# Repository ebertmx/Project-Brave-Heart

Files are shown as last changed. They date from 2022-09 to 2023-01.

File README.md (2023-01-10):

# Project Brave Heart
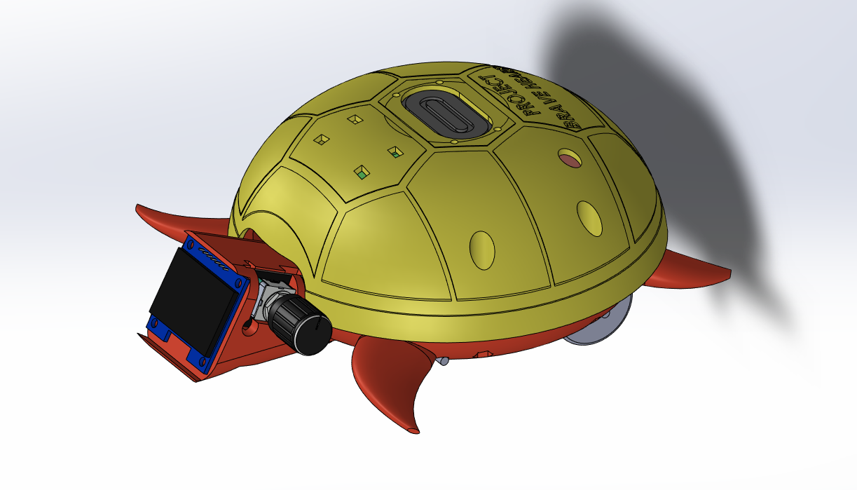
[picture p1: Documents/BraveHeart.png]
BraveHeart Model
  
 
 Project Brave Heart is a radio alarm clock assembly. This model is turtle themed and features a wheeled drive system which activates upon the alarm being triggered - causing the turtle to run away. The main components include a custom PCB, a raspberry pi Pico, and a RDA5807M radio module. A complete description and documentation can be found in this repository.

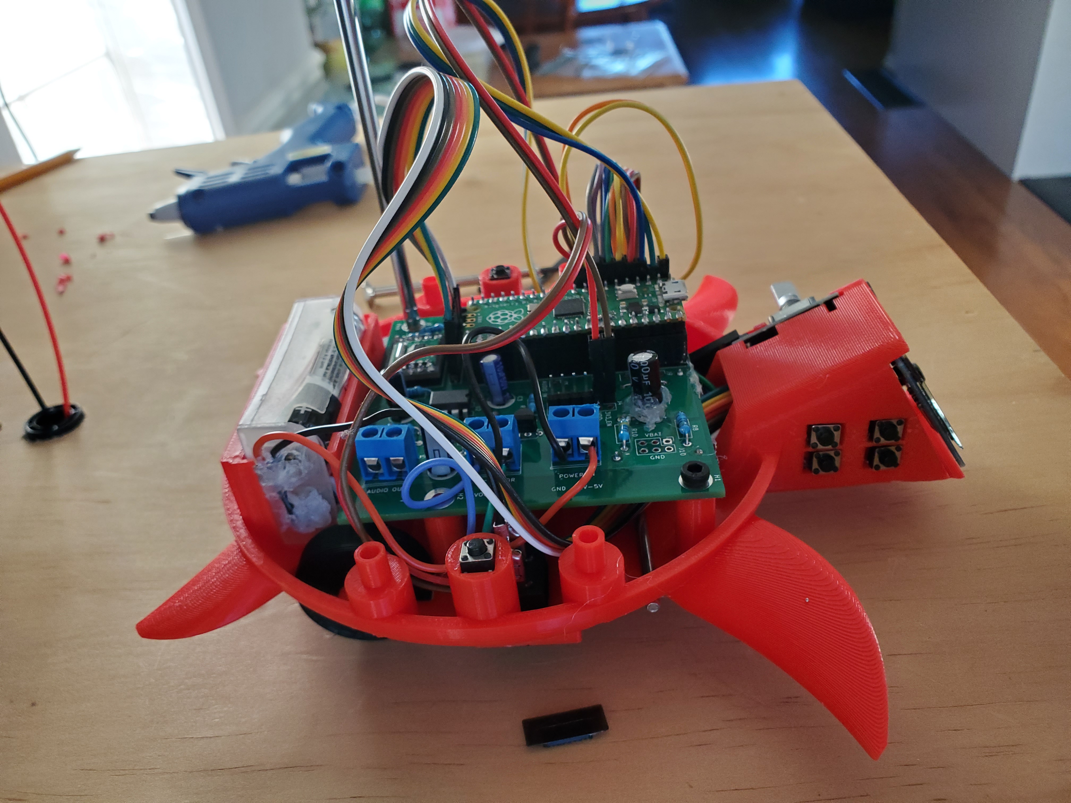
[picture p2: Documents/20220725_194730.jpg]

BraveHeart Model

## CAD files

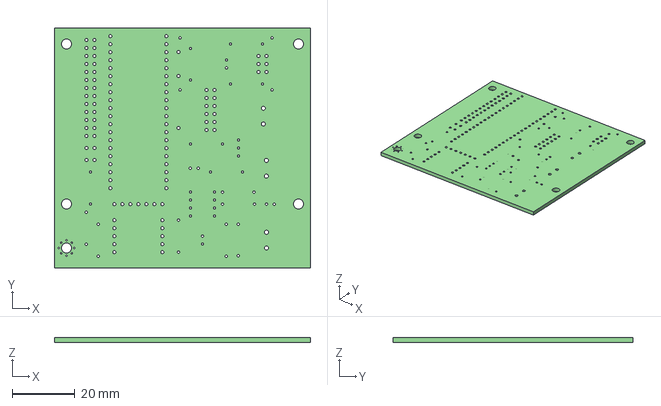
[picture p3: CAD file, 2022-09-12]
Electrical_and_PCB/project_brave_heart.step
81.3 x 76.2 x 1.60 mm

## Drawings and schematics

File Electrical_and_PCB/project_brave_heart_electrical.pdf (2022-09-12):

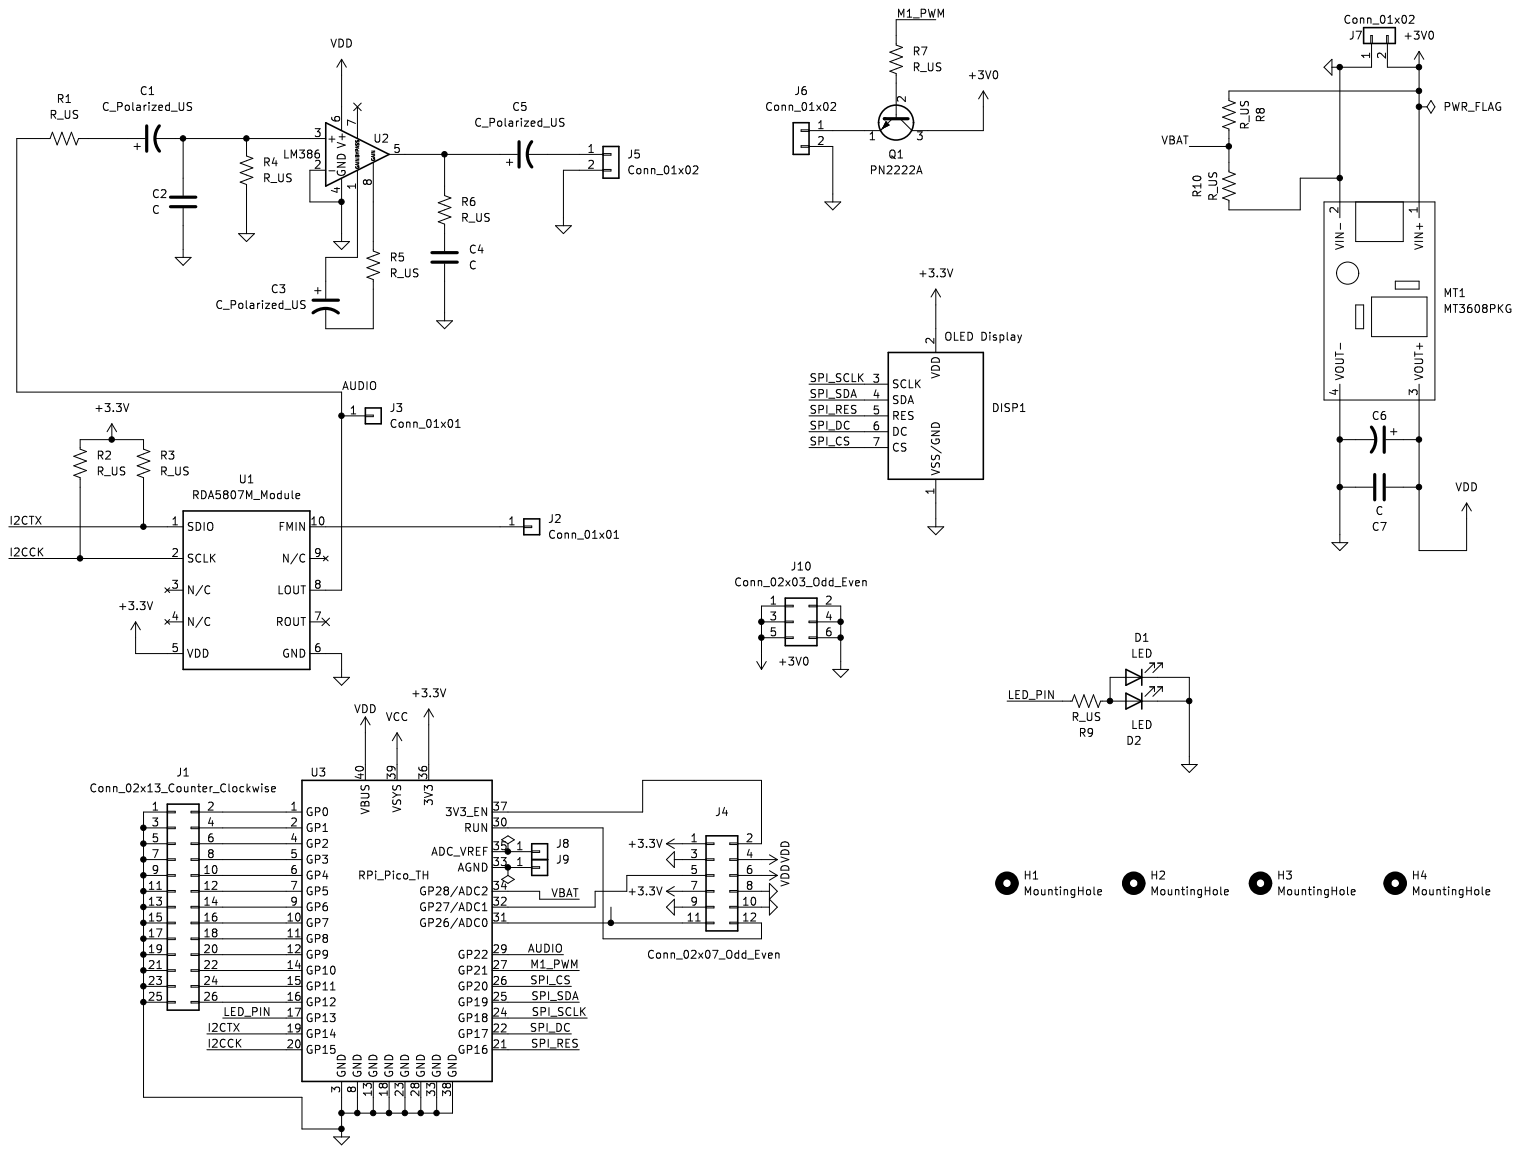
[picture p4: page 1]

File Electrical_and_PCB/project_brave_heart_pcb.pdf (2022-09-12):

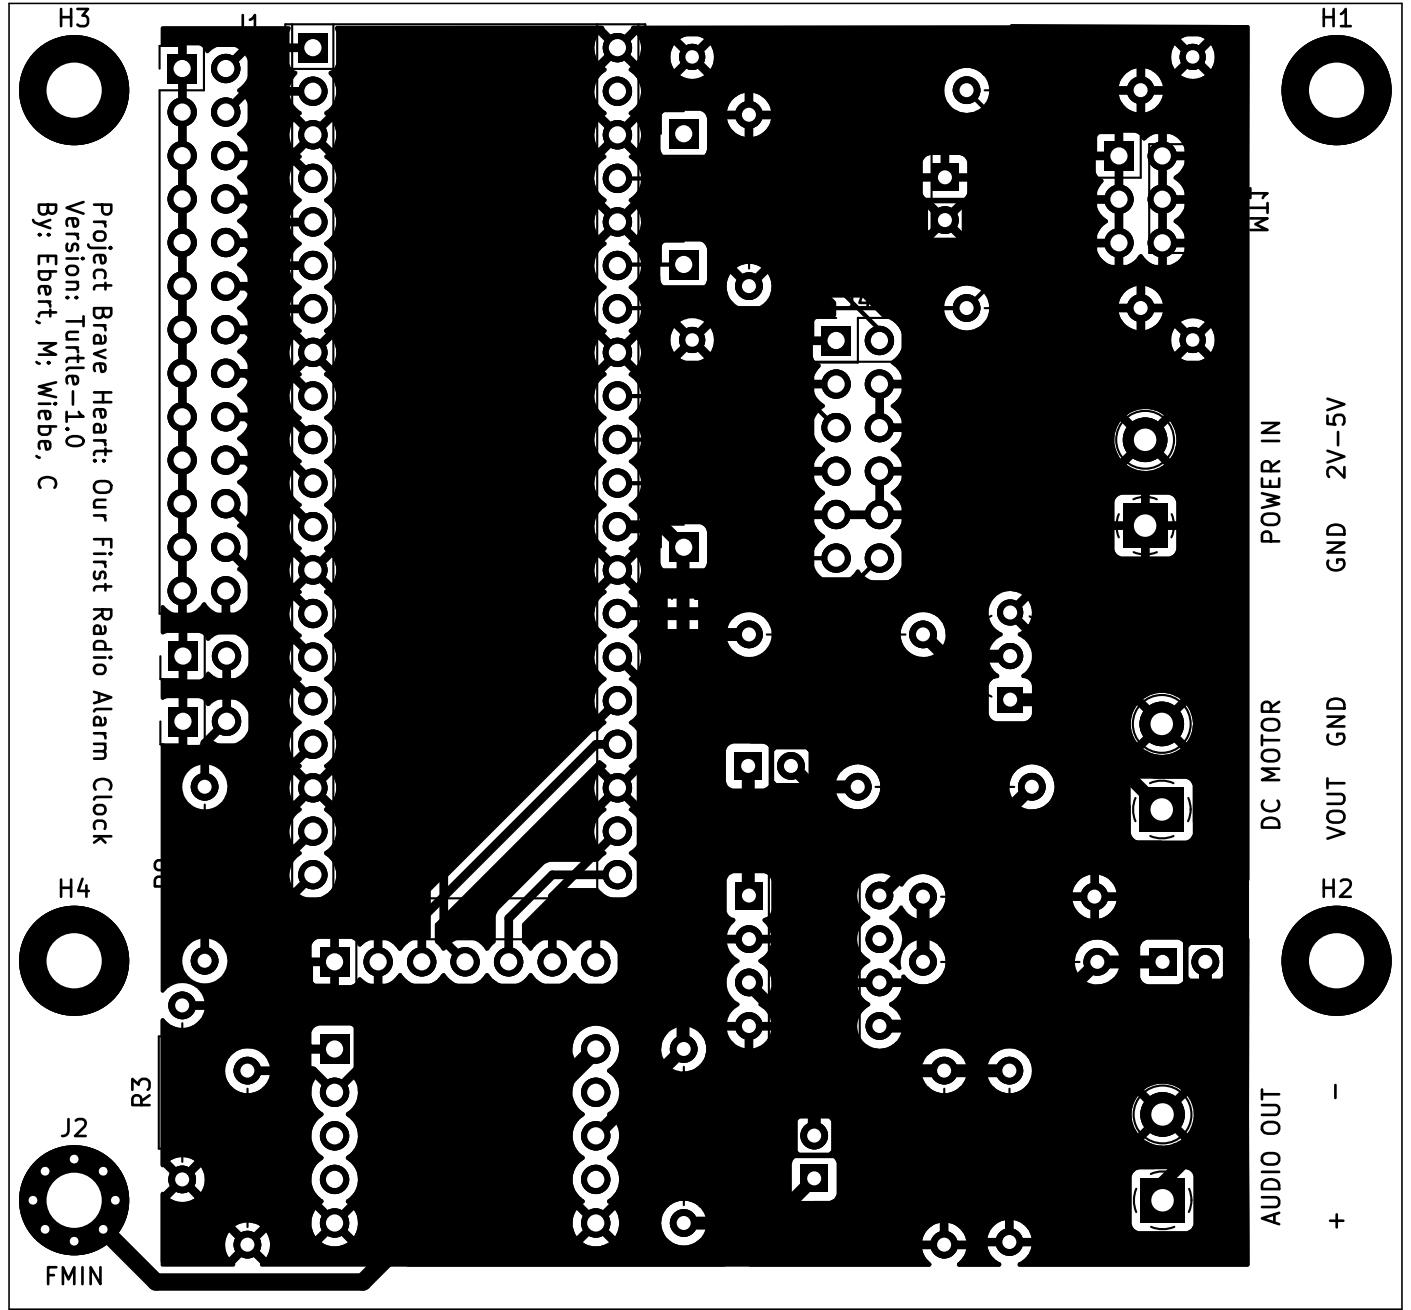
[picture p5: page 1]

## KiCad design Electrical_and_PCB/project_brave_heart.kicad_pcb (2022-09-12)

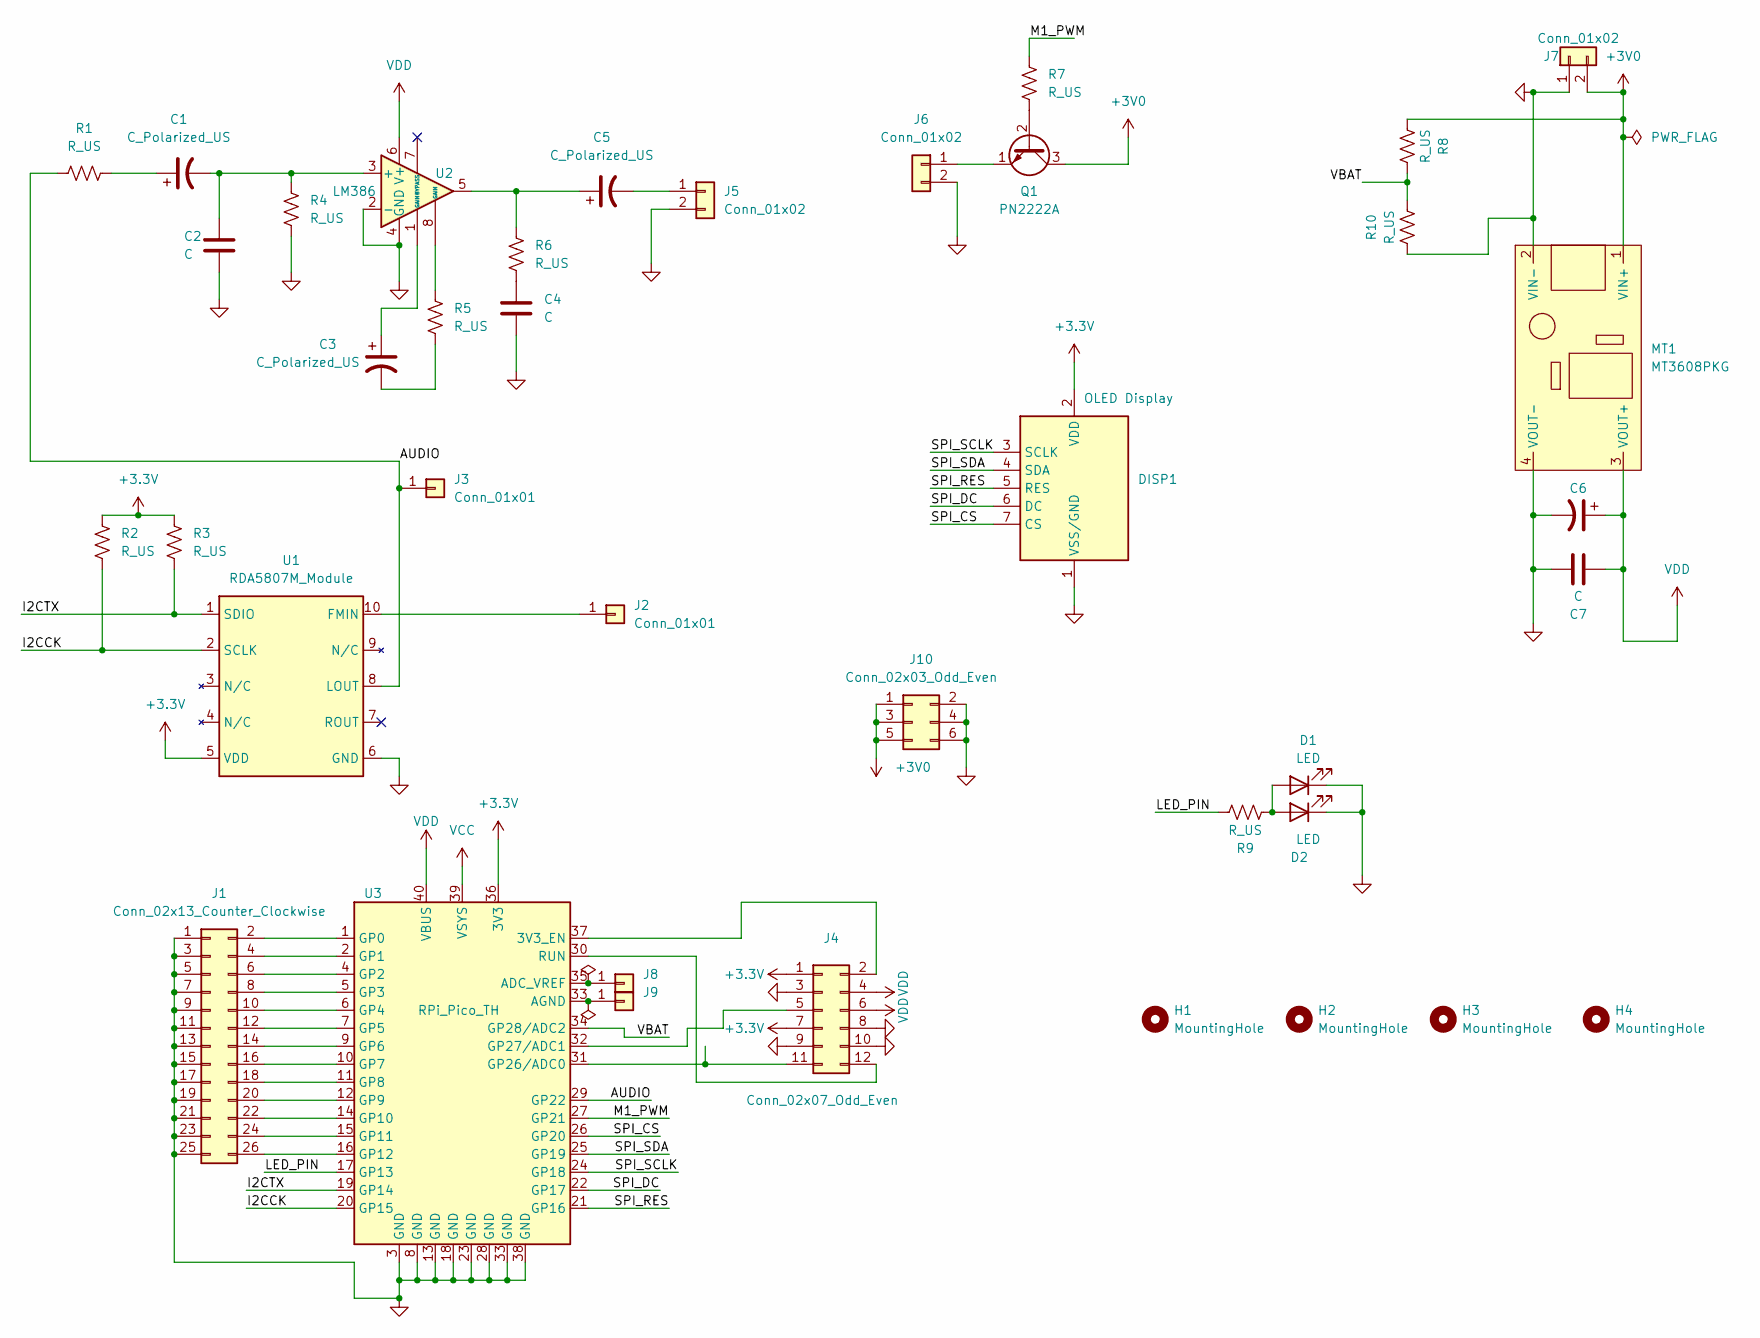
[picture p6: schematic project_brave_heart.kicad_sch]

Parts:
C1, C3, C5, C6: C_Polarized_US; CP_Radial_D6.3mm_P2.50mm
C2, C4, C7: C; C_Axial_L3.8mm_D2.6mm_P10.00mm_Horizontal
D1, D2: LED; PinHeader_1x02_P2.54mm_Vertical
DISP1: OLED Display; PinHeader_1x07_P2.54mm_Vertical
H1, H2, H3, H4: MountingHole; MountingHole_3.2mm_M3_Pad
J1: Conn_02x13_Counter_Clockwise; PinHeader_2x13_P2.54mm_Vertical
J2: Conn_01x01; MountingHole_3.2mm_M3_Pad_Via
J3, J8, J9: Conn_01x01; PinHeader_1x01_P2.54mm_Vertical
J4: Conn_02x07_Odd_Even; PinHeader_2x06_P2.54mm_Vertical
J5, J6, J7: Conn_01x02; TerminalBlock_Phoenix_MKDS-1,5-2_1x02_P5.00mm_Horizontal
J10: Conn_02x03_Odd_Even; PinHeader_2x03_P2.54mm_Vertical
MT1: MT3608PKG
Q1: PN2222A; TO-92_Inline_Wide
R1, R2, R3, R4, R5, R6, R7, R8, R9, R10: R_US; R_Axial_DIN0207_L6.3mm_D2.5mm_P10.16mm_Horizontal
U1: RDA5807M_Module; RDA5807M_Module_TH
U2: LM386; DIP-8_W7.62mm
U3: RPi_Pico_TH

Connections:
+3V0: J7.2, J10.1, J10.3, J10.5, MT1.1 (VIN+), Q1.3 (C), R8.2
+3V3: DISP1.2 (VDD), J4.1, J4.7, R2.1, R3.1, U1.5 (VDD), U3.36 (3V3)
/AUDIO: J3.1, R1.1, U1.8 (LOUT), U3.29 (GP22)
/I2CCK: R2.2, U1.2 (SCLK), U3.20 (GP15)
/I2CTX: R3.2, U1.1 (SDIO), U3.19 (GP14)
/LED_PIN: R9.1, U3.17 (GP13)
/M1_PWM: R7.1, U3.27 (GP21)
/SPI_CS: DISP1.7 (CS), U3.26 (GP20)
/SPI_DC: DISP1.6 (DC), U3.22 (GP17)
/SPI_RES: DISP1.5 (RES), U3.21 (GP16)
/SPI_SCLK: DISP1.3 (SCLK), U3.24 (GP18)
/SPI_SDA: DISP1.4 (SDA), U3.25 (GP19)
/VBAT: R8.1, R10.1, U3.34 (GP28/ADC2)
unnamed: C1.1, R1.2
unnamed: C1.2, C2.1, R4.1, U2.3 (+)
unnamed: C3.1, U2.1 (GAIN)
unnamed: C3.2, R5.2
unnamed: C4.1, R6.2
unnamed: C5.1, R6.1, U2.5
unnamed: C5.2, J5.1
unnamed: D1.2 (A), D2.2 (A), R9.2
unnamed: J1.2, U3.1 (GP0)
unnamed: J1.4, U3.2 (GP1)
unnamed: J1.6, U3.4 (GP2)
unnamed: J1.8, U3.5 (GP3)
unnamed: J1.10, U3.6 (GP4)
unnamed: J1.12, U3.7 (GP5)
unnamed: J1.14, U3.9 (GP6)
unnamed: J1.16, U3.10 (GP7)
unnamed: J1.18, U3.11 (GP8)
unnamed: J1.20, U3.12 (GP9)
unnamed: J1.22, U3.14 (GP10)
unnamed: J1.24, U3.15 (GP11)
unnamed: J1.26, U3.16 (GP12)
unnamed: J2.1, U1.10 (FMIN)
unnamed: J6.1, Q1.1 (E)
unnamed: J8.1, U3.35 (ADC_VREF)
unnamed: Q1.2 (B), R7.2
unnamed: R5.1, U2.8 (GAIN)
unnamed: J4.12, U3.30 (RUN)
unnamed: J4.11, U3.31 (GP26/ADC0)
unnamed: J4.5, U3.32 (GP27/ADC1)
unnamed: J4.2, U3.37 (3V3_EN)
VCC: U3.39 (VSYS)
VDD: C6.1, C7.2, J4.4, J4.6, MT1.3 (VOUT+), U2.6 (V+), U3.40 (VBUS)

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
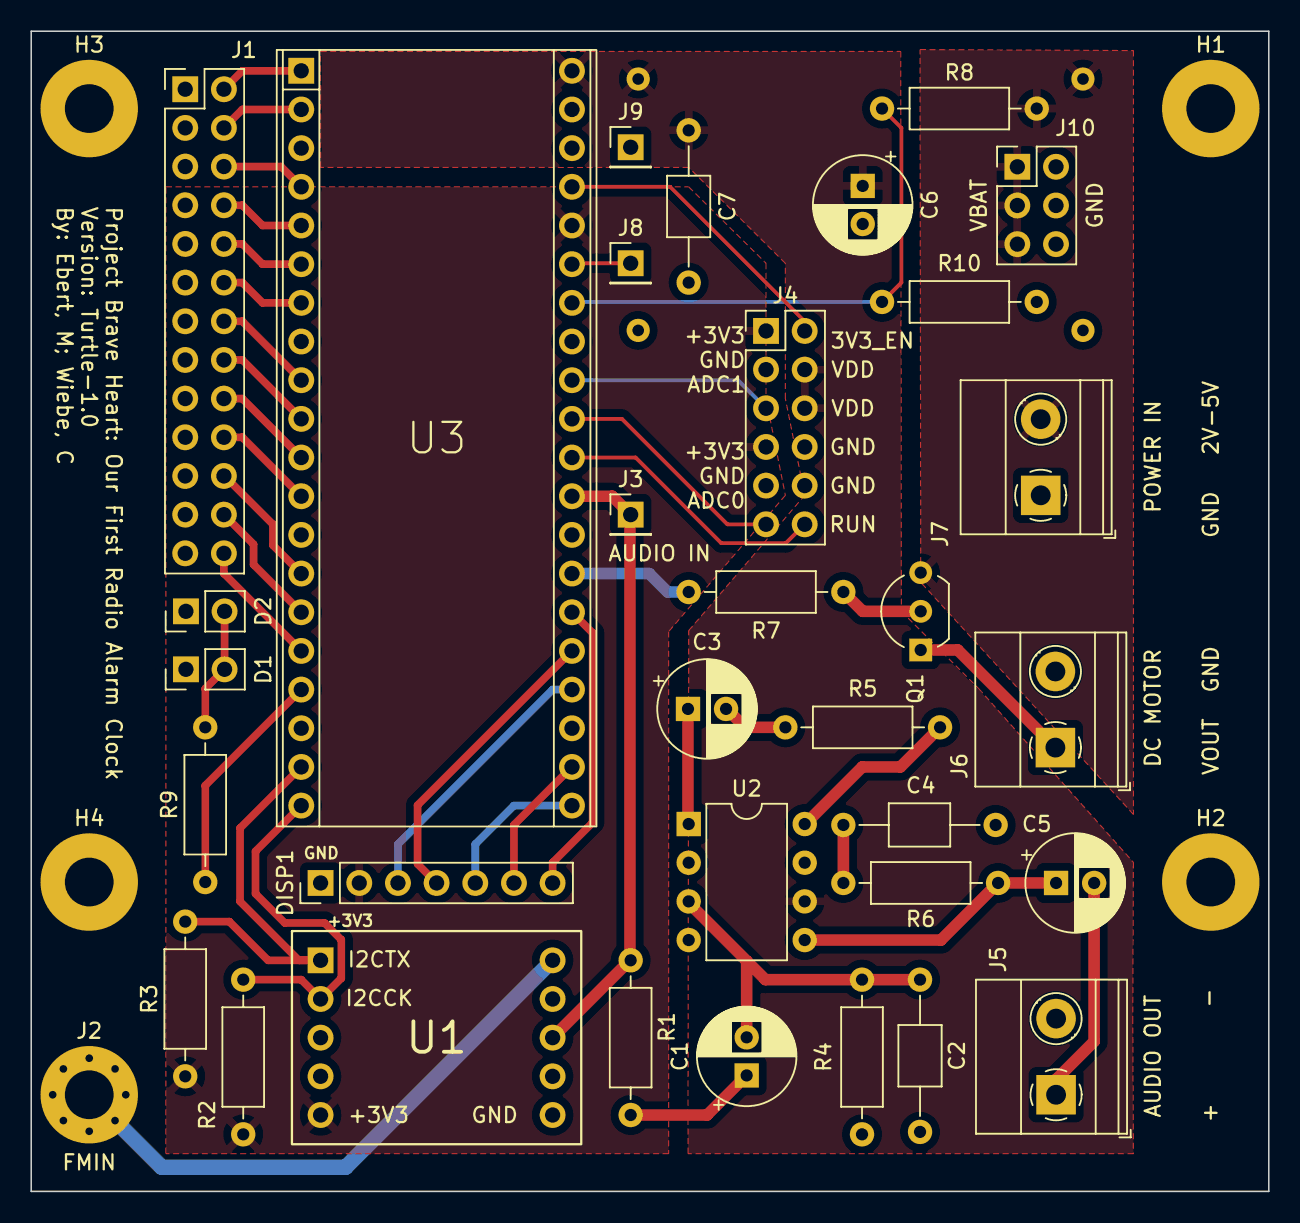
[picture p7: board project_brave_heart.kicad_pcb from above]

Board: 2 copper layers, 81.3 x 76.2 mm, 39 parts (1 on the bottom side), 45 nets.

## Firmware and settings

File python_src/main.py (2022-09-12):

#Code for alarm clock
#Connor Wiebe, Matt Ebert
#July 19 2022

#libraries to import
from machine import Pin, SPI, Timer
import utime as time
from encoder_library import RotaryIRQ
from Clock_code import Clock,Alarm
import Clock_code
from bh_fm_radio import Radio
import math
#end of libraries to import 

#button/motor setup
snooze_button1 = machine.Pin(7,machine.Pin.IN,machine.Pin.PULL_UP)
snooze_button2 = machine.Pin(8,machine.Pin.IN,machine.Pin.PULL_UP)
vol_up_button = machine.Pin(3,machine.Pin.IN,machine.Pin.PULL_UP)
vol_down_button = machine.Pin(4,machine.Pin.IN,machine.Pin.PULL_UP)
seek_button = machine.Pin(6,machine.Pin.IN,machine.Pin.PULL_UP)
mute_toggle_button = machine.Pin(5,machine.Pin.IN,machine.Pin.PULL_UP)
motor = machine.Pin(21,machine.Pin.OUT)
motor.value(0)
audio_out =machine.Pin(22,machine.Pin.OUT)
#radio_on_off = machine.Pin(8,machine.Pin.OUT)
#radio_on_off.value(0)

#end of button setup

#radio setup
fm_radio = Radio( 100.3, 2, True,9)
#end of radio setup

#encoder setup
encoder_button = machine.Pin(2, machine.Pin.IN, machine.Pin.PULL_UP)

encoder = RotaryIRQ(pin_num_clk=0,pin_num_dt=1,min_val=0,max_val=3,range_mode=RotaryIRQ.RANGE_WRAP)
#end of encoder setup

#Stuff for the oled screen

from ssd1306 import SSD1306_SPI # this is the driver library and the corresponding class
import framebuf # this is another library for the display. 
SCREEN_WIDTH = 128 #number of columns
SCREEN_HEIGHT = 64 #number of rows
spi_sck = Pin(18) # sck stands for serial clock; always be connected to SPI SCK pin of the Pico
spi_sda = Pin(19) # sda stands for serial data;  always be connected to SPI TX pin of the Pico; this is the MOSI
spi_res = Pin(16) # res stands for reset; always be connected to SPI RX pin of the Pico; this is the MISO
spi_dc  = Pin(17) # dc stands for data/commonda; always be connected to SPI CSn pin of the Pico
spi_cs  = Pin(20) # can be connected to any free GPIO pin of the Pico
SPI_DEVICE = 0 
oled_spi = SPI( SPI_DEVICE, baudrate= 100000, sck= spi_sck, mosi= spi_sda )
oled = SSD1306_SPI( SCREEN_WIDTH, SCREEN_HEIGHT, oled_spi, spi_dc, spi_res, spi_cs, True )
#End of OLED setup stuff

#Setting up varibales and classes for later
count = 0
page = 0
hour = 8
minute = 45
end_change_flag =False
am_pm = True
time_type=False
Clock = Clock(hour,minute,am_pm,time_type,False)
Alarm = Alarm(hour,minute,am_pm,time_type,set_flag=False)
#end of varibale and class setup

def motor_off(x):
    motor.value(0)
    
def vol_up(x):
    check = debounce(x)
    if check == True:
        return
    else:
        fm_radio.increase_volume()
        check_page(page)
def vol_down(x):
    check = debounce(x)
    if check == True:
        return
    else:
        fm_radio.decrease_volume()
        check_page(page)
def snooze(x):
    check = debounce(x)
    if check == True:
        return
    else:
        #motor.value(1)
        #time.sleep(2)
        motor.value(0)
        print("snoozed")
        Alarm.snooze(Clock,fm_radio)
def mute_toggle(x):
    check = debounce(x)
    if check == True:
        return
    else:
        fm_radio.toggle_mute()
        check_page(page)            
def seek(x):
    #print(fm_radio.get_Frequency())
    check = debounce(x)
    if check == True:
        return
    else:
        fm_radio.Seek()
        check_page(page)

def update_time(x):#function for updating and displaying clock time 
    if page == 0 or page==1:
        oled.text("%02d:%02d %s" %(Clock.get_hour(),Clock.get_minute(),Clock.get_am_pm()),25,0,0)
        Clock.update()
        Alarm.pop_off(Clock,fm_radio)
        oled.text("%02d:%02d %s" %(Clock.get_hour(),Clock.get_minute(),Clock.get_am_pm()),25,0,1)
        oled.show()
    else:
        Clock.update()
        Alarm.pop_off(Clock,fm_radio)
    if fm_radio.get_mute()==False:
            oled.text("Mute",0,55,0)
    if Alarm.goin_off==True:
          #print("motor 1")
          time.sleep(0.01)
          motor.value(1)
          #print("motor 2")
          #time.sleep(2)
          #motor.value(0)
          #print("motor 3")
        #check_page(page)
def update_radio(x):
    if page ==0:
        oled.fill_rect(0,35,300,10,0)
        oled.text(fm_radio.GetInfo(),15,35)
        oled.show()
        
        
def debounce(x):#function for debouncing the button
   state =0xff
   i=0
   while i<16:
       i=i+1
      # print(x.value()|0x00)
       state = ((state<<1) | (x.value() | 0x00)) & 0xFF 
       #print(hex(state))
   if (state == 0x00):
       return False
   else:
       return True
    
def work(x):#main encoder press function
    #debounce check
    check = debounce(x)
    if check == True:
        return
    #end of debounce check
    else:#main bulk of the function
        global page
        global count
        if page==0 or page==1:
            print("press")
            if page == 0:
                if encoder.value() == 0:#set alarm
                    page = 3
                #print("notyet")
                elif encoder.value() == 1:#set radio 
                    page =4
                if encoder.value() == 2:#radio info button
                    #print("radio not done yet")
                    page =5
                if encoder.value() ==3:#next button
                    page = 1
                    encoder.set(value = 0,min_val=0,max_val=3,range_mode=RotaryIRQ.RANGE_WRAP)
            elif page == 1:
                if encoder.value() == 0:#set clock
                    #print("here")
                    page =2
                elif encoder.value() == 1:#toggle 12/24hr time
                   Clock.time_type_change(not Clock.get_time_type())
                   Alarm.time_type_change(Clock.get_time_type())
                elif encoder.value() ==2:#toggle alarm
                    Alarm.update_set_flag()
                elif encoder.value() == 3:#prev button
                    page = 0
                    encoder.set(value = 0,min_val=0,max_val=3,range_mode=RotaryIRQ.RANGE_WRAP)
        if page==2 or page==3:
            #print("clock change press")
            count = count+1 #incrementing the varible to indicate which step we are on
            if Clock.get_time_type() == False:
                if count>3:#set the encoder back to values for main pages
                    #page=0
                    encoder.set(value = 0,min_val=0,max_val=3,range_mode=RotaryIRQ.RANGE_WRAP)
            elif Clock.get_time_type() == True:
                if count>2:#set the encoder back to values for main pages
                    #page=0
                    encoder.set(value = 0,min_val=0,max_val=3,range_mode=RotaryIRQ.RANGE_WRAP)
        if page ==4:
            count+=1#incrementing the varible to indicate which step we are on
            if count>2:#set the encoder back to values for main pages
                encoder.set(value = 0,min_val=0,max_val=3,range_mode=RotaryIRQ.RANGE_WRAP)
        if page==5:#set encoder back to values for main pages
            if encoder.value()==0:
                page=0
                encoder.set(value = 0,min_val=0,max_val=3,range_mode=RotaryIRQ.RANGE_WRAP)
            
                
            
        check_page(page)                
        
def check_page(page):#function to display correct stuff for page on screen and update encoder values
    mute_stat,vol_stat,freq_stat,sterio_stat=fm_radio.GetSettings()
    if page ==0:#this is to display page 0
        oled.fill(0)
        oled.text("%02d"%vol_stat,0,0)
        oled.text("%02d:%02d %s" %(Clock.get_hour(),Clock.get_minute(),Clock.get_am_pm()),25,0)
        oled.text("Set Alarm",15,15)
        oled.text("Set Radio",15,25)
        #oled.text("Radio Info",15,35)
        oled.text("Next ->",15,45)
        if fm_radio.get_mute()==True:
            oled.text("Mute",0,55,1)
        elif fm_radio.get_mute()==False:
            oled.text("Mute",0,55,0)
        if Alarm.get_set_flag()==True:
            oled.text("Armd",98,0)
        oled.text("%.2f FM"%freq_stat,35,55)
        oled.show()
    elif page==1:#this is to display page 1
        oled.fill(0)
        oled.text("%02d"%vol_stat,0,0)
        oled.text("%02d:%02d %s" %(Clock.get_hour(),Clock.get_minute(),Clock.get_am_pm()),25,0)
        oled.text("Set Clock",15,15)
        oled.text("12/24 hour",15,25)
        oled.text("Alarm On/Off",15,35)
        oled.text("<- Prev",15,45)
        if fm_radio.get_mute()==True:
            oled.text("Mute",0,55,1)
        elif fm_radio.get_mute()==False:
            oled.text("Mute",0,55,0)            
        if Alarm.get_set_flag()==True:
            oled.text("Armd",98,0)
        oled.text("%.2f FM"%freq_stat,35,55)
        oled.show()
    elif page==2 or page==3: #this is to change the encoder to have valid values for the clock
        oled.fill(0)
        if Clock.time_type == False: #12hr time
            if count ==1:
                #oled.text("Change Minute:",25,25,1)
                encoder.set(value = 0,min_val=0,max_val=59,range_mode=RotaryIRQ.RANGE_WRAP)
            if count ==2:
                encoder.set(value = 1,min_val=1,max_val=12,range_mode=RotaryIRQ.RANGE_WRAP)
                #oled.text("Change Minute:",25,25,0)
                #oled.text("Change Hour:",25,25,1)
            if count ==3:
                encoder.set(value = 0,min_val=0,max_val=1,range_mode=RotaryIRQ.RANGE_WRAP)
                #oled.text("Change Hour:",25,25,0)
                #oled.text("Am or Pm?",25,25,1)
            #if count>3:
               # page=0
        else:
            if count ==1:
                encoder.set(value = 0,min_val=0,max_val=59,range_mode=RotaryIRQ.RANGE_WRAP)
                #oled.text("Change Minute",25,25,1)
            if count ==2:
                encoder.set(value = 0,min_val=0,max_val=23,range_mode=RotaryIRQ.RANGE_WRAP)
                #oled.text("Change Minute",25,25,0)
                #oled.text("Change Hour",25,25,1)
           # if count>2:
             #   page=0
    elif page ==4:#set encoder values for the radio
        oled.fill(0)
        if count ==1:
            encoder.set(value = 0,min_val=0,max_val=9,range_mode=RotaryIRQ.RANGE_WRAP)
        if count ==2:
            encoder.set(value = 88,min_val=88,max_val=108,range_mode=RotaryIRQ.RANGE_WRAP)
    elif page==5:#essentially make the encoder a back button
        encoder.set(value = 0,min_val=0,max_val=0,range_mode=RotaryIRQ.RANGE_WRAP)
        oled.fill(0)
        
        
oled.fill(0)
oled.text("%02d"%fm_radio.get_volume(),0,0)
oled.text("%02d:%02d %s" %(Clock.get_hour(),Clock.get_minute(),Clock.get_am_pm()),25,0)
oled.text("Set Alarm",15,15)
oled.text("Set Radio",15,25)
#oled.text("Radio Info",15,35)
oled.text("Next ->",15,45)
oled.text("%.2f FM"%fm_radio.get_Frequency(),35,55)
if fm_radio.get_mute()==True:
            oled.text("Mute",0,55,1)
elif fm_radio.get_mute()==False:
            oled.text("Mute",0,55,0) 
oled.show()
clk_update = Timer(-1)
clk_update.init(period=600,callback=update_time)
radio_update = Timer(-1)
radio_update.init(period=300,callback=update_radio)

#interrupt handler setup
encoder_button.irq(trigger=machine.Pin.IRQ_FALLING, handler=work)
seek_button.irq(trigger=machine.Pin.IRQ_FALLING, handler=seek)
snooze_button1.irq(trigger=machine.Pin.IRQ_FALLING, handler=snooze)
snooze_button2.irq(trigger=machine.Pin.IRQ_FALLING, handler=snooze)
vol_up_button.irq(trigger=machine.Pin.IRQ_FALLING, handler=vol_up)
vol_down_button.irq(trigger=machine.Pin.IRQ_FALLING, handler=vol_down)
mute_toggle_button.irq(trigger=machine.Pin.IRQ_FALLING, handler=mute_toggle)
#end of interuppt handler setup
#radio bug stoppage
mute_stat,vol_stat,freq_stat,sterio_stat=fm_radio.GetSettings()
if freq_stat>108:
    print("called")
    fm_radio.DefaultSettings()
#end of radio bug stoppage
while (True):
    #print(fm_radio.GetInfo())
    #print(encoder.value())
    if page==1 or page ==0:#this is for using the 2 main pages
        #update_radio()
        if encoder.value() == 0:
            #oled.fill(0)
            oled.text(">",0,25,0)
            oled.text(">",0,35,0)
            oled.text(">",0,15,1)
            oled.text(">",0,45,0)
            #oled.show()
        elif encoder.value() == 1:
            #oled.fill(0)
            oled.text(">",0,25,1)
            oled.text(">",0,35,0)
            oled.text(">",0,15,0)
            #oled.show()
        elif encoder.value() == 2:
            #oled.fill(0)
            oled.text(">",0,25,0)
            oled.text(">",0,35,1)
            oled.text(">",0,15,0)
            oled.text(">",0,45,0)
        elif encoder.value() == 3:
            #oled.fill(0)
            oled.text(">",0,15,0)
            oled.text(">",0,25,0)
            oled.text(">",0,35,0)
            oled.text(">",0,45,1)
            #oled.show()
        oled.show()
    if page==4:#page for setting radio frequency
        init_freq = fm_radio.get_Frequency()
        radio_freq_dec, radio_freq_main = math.modf(init_freq)
        radio_freq_dec = radio_freq_dec*100
        radio_freq_dec = int(radio_freq_dec)
        radio_freq_main = int(radio_freq_main)
        while (True):
            #print("oops")
            if count>2:#statement to end the loop an revert to main operation
                count =0
                page =1
                final_freq = float(radio_freq_main)+float(radio_freq_dec)/10
                fm_radio.SetFrequency(final_freq)
                fm_radio.SetMute(False)
                end_change_flag = True
                fm_radio.ProgramRadio()
                break
            oled.fill(0)
            oled.text("Set Radio Frequency:",15,0)
            if count ==1:
                oled.text("%2d.%02d"%(radio_freq_main,encoder.value()),25,45)
                radio_freq_dec=encoder.value()
            if count ==2:
                oled.text("%2d.%02d"%(encoder.value(),radio_freq_dec),25,45)
                radio_freq_main=encoder.value()
            oled.show()
    if page ==5: #this page displays the radio information
        mute_stat,vol_stat,freq_stat,sterio_stat=fm_radio.GetSettings()
        #next 2 if statements are to print if mute is true or false
        if mute_stat ==1:
            mute_stat_string = "True"
        elif mute_stat==0:
            mute_stat_string = "False"
        oled.fill(0)
        oled.text("Radio Freq:",0,0)
        oled.text("           %2f FM"%freq_stat,0,0)
        oled.text("Mute: %s"%mute_stat_string,0,25)
        oled.text("Volume: %d"%vol_stat,0,35)
        oled.text("Station Info: %s"%sterio_stat,0,15)
        oled.text("<- Back",0,45)
        oled.show()
        
                
            
    if page ==2 or page==3:#this if statement is for setting the clock
        while (True):
            if page==3: #this page is for setting the alarm
                if Alarm.time_type == False: #12hr time
                    if count>3:#statement to end the loop an revert to main operation
                        count=0
                        page=0
                        Alarm.set_flag=True
                        end_change_flag = True
                        print("broken")
                        break
                    oled.fill(0)
                    oled.text("Set Alarm:",25,0)
                    if count ==1:
                        oled.text("Change Minute:",25,25,1)
                        oled.text("%02d:    %s" %(Alarm.get_hour(),Alarm.get_am_pm()),25,45)
                        oled.text("    %02d"%encoder.value(),25,45,1)
                        #oled.text("    %2d"%encoder.value(),25,45,0)
                        Alarm.minute_set(encoder.value())
                        #print(page)
                    if count ==2:
                        oled.text("   :%02d %s" %(Alarm.get_minute(),Alarm.get_am_pm()),25,45)
                        oled.text("%02d"%encoder.value(),25,45,1)
                        #oled.text("%2d"%encoder.value(),25,45,0)
                        oled.text("Change Minute:",25,25,0)
                        oled.text("Change Hour:",25,25,1)
                        Alarm.hour_set(encoder.value())
                    if count ==3:
                        oled.text("%02d:%02d " %(Alarm.get_hour(),Alarm.get_minute()),25,45)
                        oled.text("        %s"%Alarm.get_am_pm(),25,45,1)
                        #oled.text("        %s"%Clock.get_am_pm(),25,45,0)
                        oled.text("Change Hour:",25,25,0)
                        oled.text("Am or Pm?",25,25,1)
                        Alarm.am_pm_set(encoder.value())
                    oled.show()
                else: #24 hr time
                    if count>2:#statement to end the loop an revert to main operation
                        count=0
                        page=0
                        Alarm.set_flag=True
                        end_change_flag = True
                        break
                    oled.fill(0)
                    oled.text("Change Time:",25,0)
                    if count ==1:
                        oled.text("%02d:%02d" %(Alarm.get_hour(),encoder.value()),25,45)
                        oled.text("Change Minute:",25,25,1)
                        Alarm.minute_set(encoder.value())
                    if count ==2:
                        oled.text("%02d:%02d" %(encoder.value(),Alarm.get_minute()),25,45)
                        oled.text("Change Minute:",25,25,0)
                        oled.text("Change Hour:",25,25,1)
                        Alarm.hour_set(encoder.value())
                    oled.show()
                    
                
                oled.show()
            if page ==2: #this page is for setting the clock
                if Clock.time_type == False: #12hr time
                    if count>3:#statement to end the loop an revert to main operation
                        count=0
                        page=0
                        end_change_flag = True
                        print("broken")
                        break
                    oled.fill(0)
                    oled.text("Change Time:",25,0)
                    if count ==1:
                        oled.text("Change Minute:",25,25,1)
                        oled.text("%2d:    %s" %(Clock.get_hour(),Clock.get_am_pm()),25,45)
                        oled.text("    %2d"%encoder.value(),25,45,1)
                        #oled.text("    %2d"%encoder.value(),25,45,0)
                        Clock.minute_set(encoder.value())
                        #print(page)
                    if count ==2:
                        oled.text("   :%2d %s" %(Clock.get_minute(),Clock.get_am_pm()),25,45)
                        oled.text("%2d"%encoder.value(),25,45,1)
                        #oled.text("%2d"%encoder.value(),25,45,0)
                        oled.text("Change Minute:",25,25,0)
                        oled.text("Change Hour:",25,25,1)
                        Clock.hour_set(encoder.value())
                    if count ==3:
                        oled.text("%2d:%2d " %(Clock.get_hour(),Clock.get_minute()),25,45)
                        oled.text("        %s"%Clock.get_am_pm(),25,45,1)
                        #oled.text("        %s"%Clock.get_am_pm(),25,45,0)
                        oled.text("Change Hour:",25,25,0)
                        oled.text("Am or Pm?",25,25,1)
                        Clock.am_pm_set(encoder.value())
                    oled.show()
                else:
                    if count>2:#statement to end the loop an revert to main operation
                        count=0
                        page=0
                        end_change_flag = True
                        break
                    oled.fill(0)
                    oled.text("Change Time:",25,0)
                    if count ==1:
                        oled.text("%2d:%2d" %(Clock.get_hour(),encoder.value()),25,45)
                        oled.text("Change Minute:",25,25,1)
                        Clock.minute_set(encoder.value())
                    if count ==2:
                        oled.text("%2d:%2d" %(encoder.value(),Clock.get_minute()),25,45)
                        oled.text("Change Minute:",25,25,0)
                        oled.text("Change Hour:",25,25,1)
                        Clock.hour_set(encoder.value())
                    oled.show()
                    
                
                oled.show()
    if end_change_flag ==True:
        end_change_flag =False
        check_page(page)
        
    

    

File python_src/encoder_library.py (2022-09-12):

# The MIT License (MIT)
# Copyright (c) 2020 Mike Teachman
# Copyright (c) 2021 Eric Moyer
# https://opensource.org/licenses/MIT

# Platform-specific MicroPython code for the rotary encoder module
# Raspberry Pi Pico implementation

# Documentation:
#   https://github.com/MikeTeachman/micropython-rotary

from machine import Pin
from rotary import Rotary

IRQ_RISING_FALLING = Pin.IRQ_RISING | Pin.IRQ_FALLING


class RotaryIRQ(Rotary):
    def __init__(
        self,
        pin_num_clk,
        pin_num_dt,
        min_val=0,
        max_val=10,
        reverse=False,
        range_mode=Rotary.RANGE_UNBOUNDED,
        pull_up=False,
        half_step=False,
        invert=False,
    ):
        super().__init__(min_val, max_val, reverse, range_mode, half_step, invert)

        if pull_up:
            self._pin_clk = Pin(pin_num_clk, Pin.IN, Pin.PULL_UP)
            self._pin_dt = Pin(pin_num_dt, Pin.IN, Pin.PULL_UP)
        else:
            self._pin_clk = Pin(pin_num_clk, Pin.IN)
            self._pin_dt = Pin(pin_num_dt, Pin.IN)

        self._hal_enable_irq()

    def _enable_clk_irq(self):
        self._pin_clk.irq(self._process_rotary_pins, IRQ_RISING_FALLING)

    def _enable_dt_irq(self):
        self._pin_dt.irq(self._process_rotary_pins, IRQ_RISING_FALLING)

    def _disable_clk_irq(self):
        self._pin_clk.irq(None, 0)

    def _disable_dt_irq(self):
        self._pin_dt.irq(None, 0)

    def _hal_get_clk_value(self):
        return self._pin_clk.value()

    def _hal_get_dt_value(self):
        return self._pin_dt.value()

    def _hal_enable_irq(self):
        self._enable_clk_irq()
        self._enable_dt_irq()

    def _hal_disable_irq(self):
        self._disable_clk_irq()
        self._disable_dt_irq()

    def _hal_close(self):
        self._hal_disable_irq()
